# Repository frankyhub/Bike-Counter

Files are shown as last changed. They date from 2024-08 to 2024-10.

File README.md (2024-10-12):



<div align="center">

|[:skull:ISSUE](https://github.com/frankyhub/Bike-Counter/issues?q=is%3Aissue)|[:speech_balloon: Forum /Discussion](https://github.com/frankyhub/Bike-Counter/discussions)|[:grey_question:WiKi](https://github.com/frankyhub/Bike-Counter/wiki)||
|--|--|--|--|
| | | | |
||<a href="https://github.com/frankyhub/Bike-Counter/issues">|<a href="https://github.com/frankyhub/Bike-Counter/discussions">|<a href="https://github.com/frankyhub/Bike-Counter/releases">|
|| <a href="https://github.com/frankyhub/Bike-Counter/pulse" alt="Activity">| <a href="https://github.com/frankyhub/Bike-Counter/graphs/traffic">  |<a href="https://github.com/frankyhub?tab=stars"> |
</div>

# Bike-Counter

## Story
Der Bike-Counter zählt Bikes auf einer Nebenstraße in zwei unterschiedlichen Richtungen und sendet die Zählerstände an eine SQL-Datenbank. Es sollen nur Bikes gezählt werden und keine Fußgänger oder andere Fahrzeuge. Mit einem Dashboard werden die Zählerstände der Bikes angezeigt. Eine Auswertung zeigt die Durchfahrt der Bikes innerhalb der letzten 24 Stunden. Für die Erfassung der Bikes werden 2 Lichtschranken verwendet.

Vorteile des Bike-Counters: 
+ Verwendung von handelsüblichen Sensoren (Drucksensor, Lichtschranke ...)
+ Richtungserkennung der Fahrräder
+ Zählerstände auf einem Dashboard visualisiert
+ Auswertung der Bewegungen der letzten 24h
+ Nutzung der kostenlosen SQL-Datenbank des Providers (Strato)

## Hardware
+ 1 x ESP32
+ 2 x Lichtschranken PEM2D
+ 1 x Platine (Richtungserkennung)

## Software
+ Die Zählimpulse der Lichtschranken werden von der "Richtungserkennung-Platine" aufbereitet.
+ Der ESP32 übermittelt die Zählerstände an das PHP-Programm "post-data.php".
+ Die Zählerstände werden in einer SQL-Datenbank gespeichert und mit dem Dashboard "hoki-counter.php angezeigt.
+ Eine 24h-Auswertung kann mit dem Programm "auswertung.php" erfolgen.

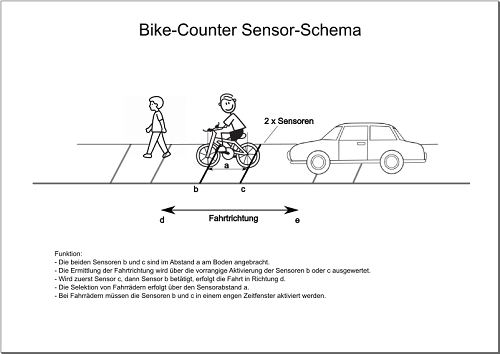
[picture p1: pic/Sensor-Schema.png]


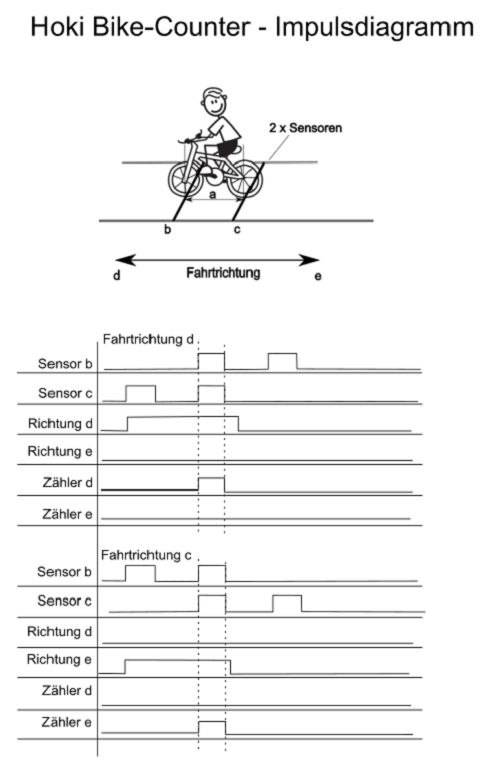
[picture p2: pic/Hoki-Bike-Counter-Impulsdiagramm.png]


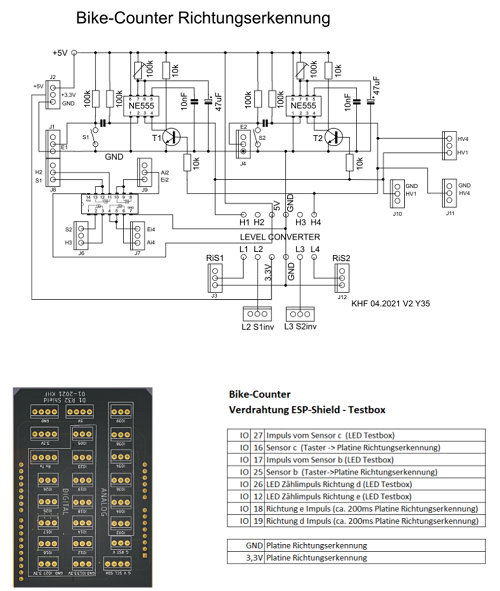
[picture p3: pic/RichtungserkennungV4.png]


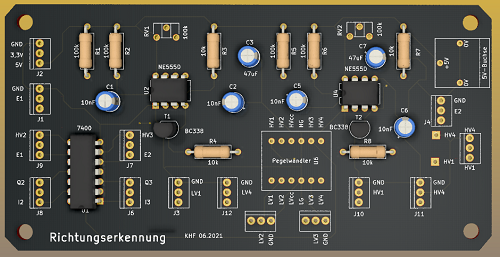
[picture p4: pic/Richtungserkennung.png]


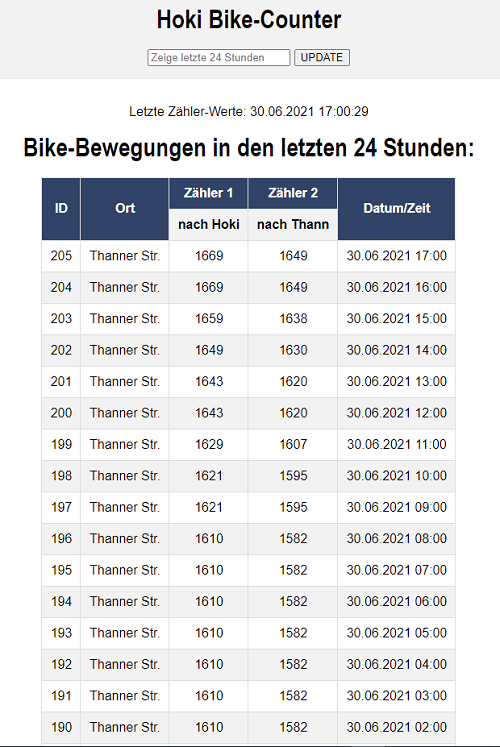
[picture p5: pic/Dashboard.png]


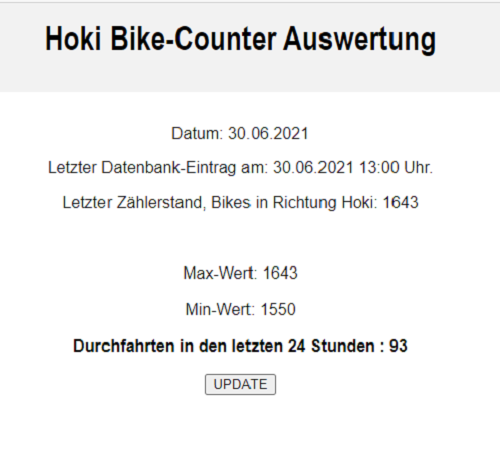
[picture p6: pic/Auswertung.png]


---

<div style="position:absolute; left:2cm; ">   
<ol class="breadcrumb" style="border-top: 2px solid black;border-bottom:2px solid black; height: 45px; width: 900px;"> <p align="center"><a href="#oben">nach oben</a></p></ol>
</div>  

---

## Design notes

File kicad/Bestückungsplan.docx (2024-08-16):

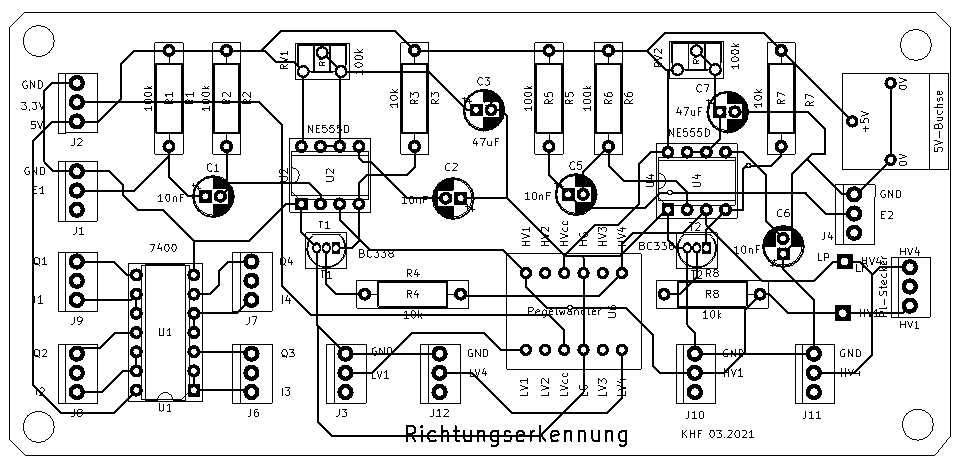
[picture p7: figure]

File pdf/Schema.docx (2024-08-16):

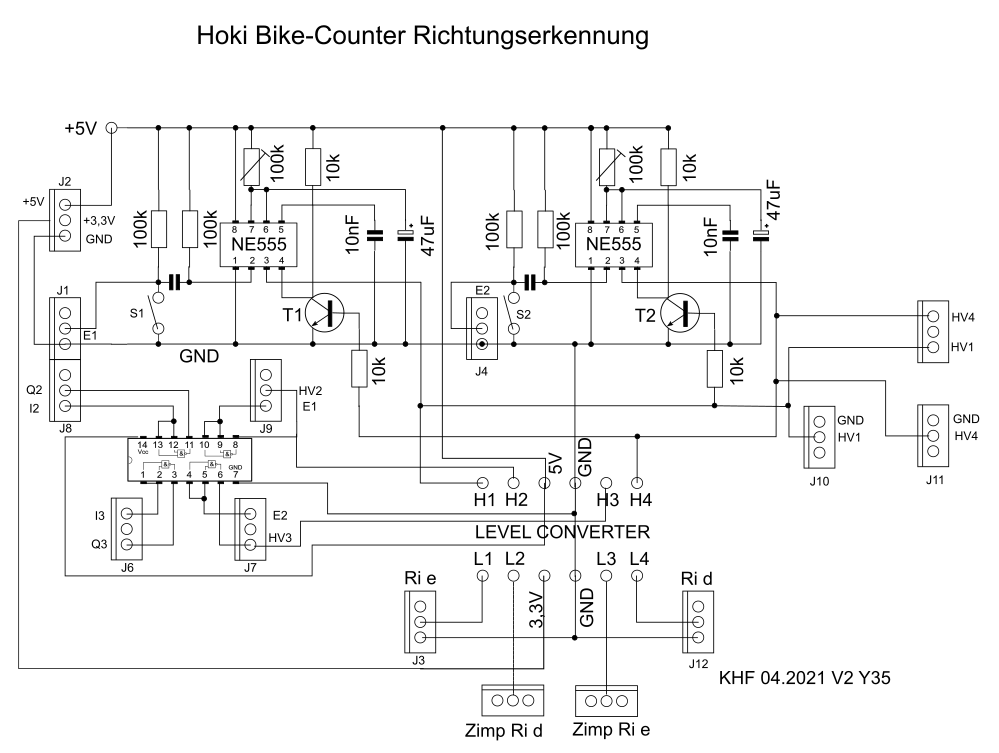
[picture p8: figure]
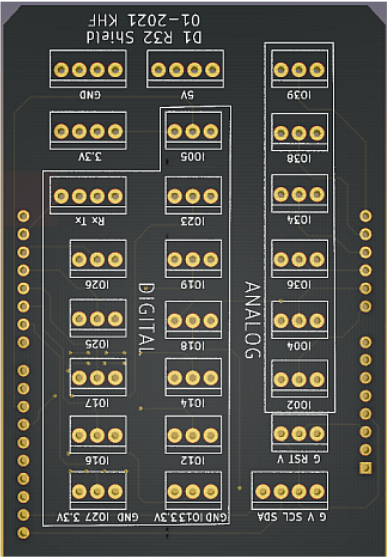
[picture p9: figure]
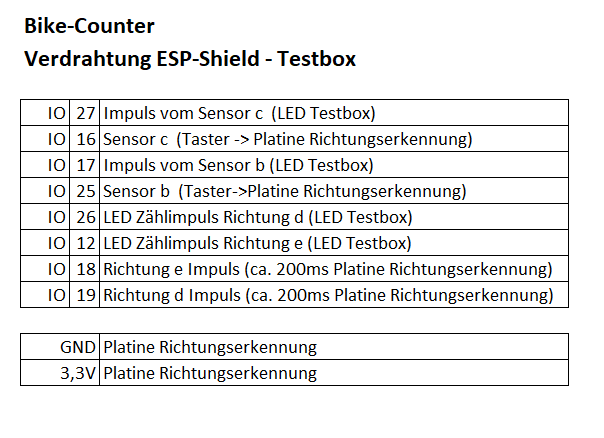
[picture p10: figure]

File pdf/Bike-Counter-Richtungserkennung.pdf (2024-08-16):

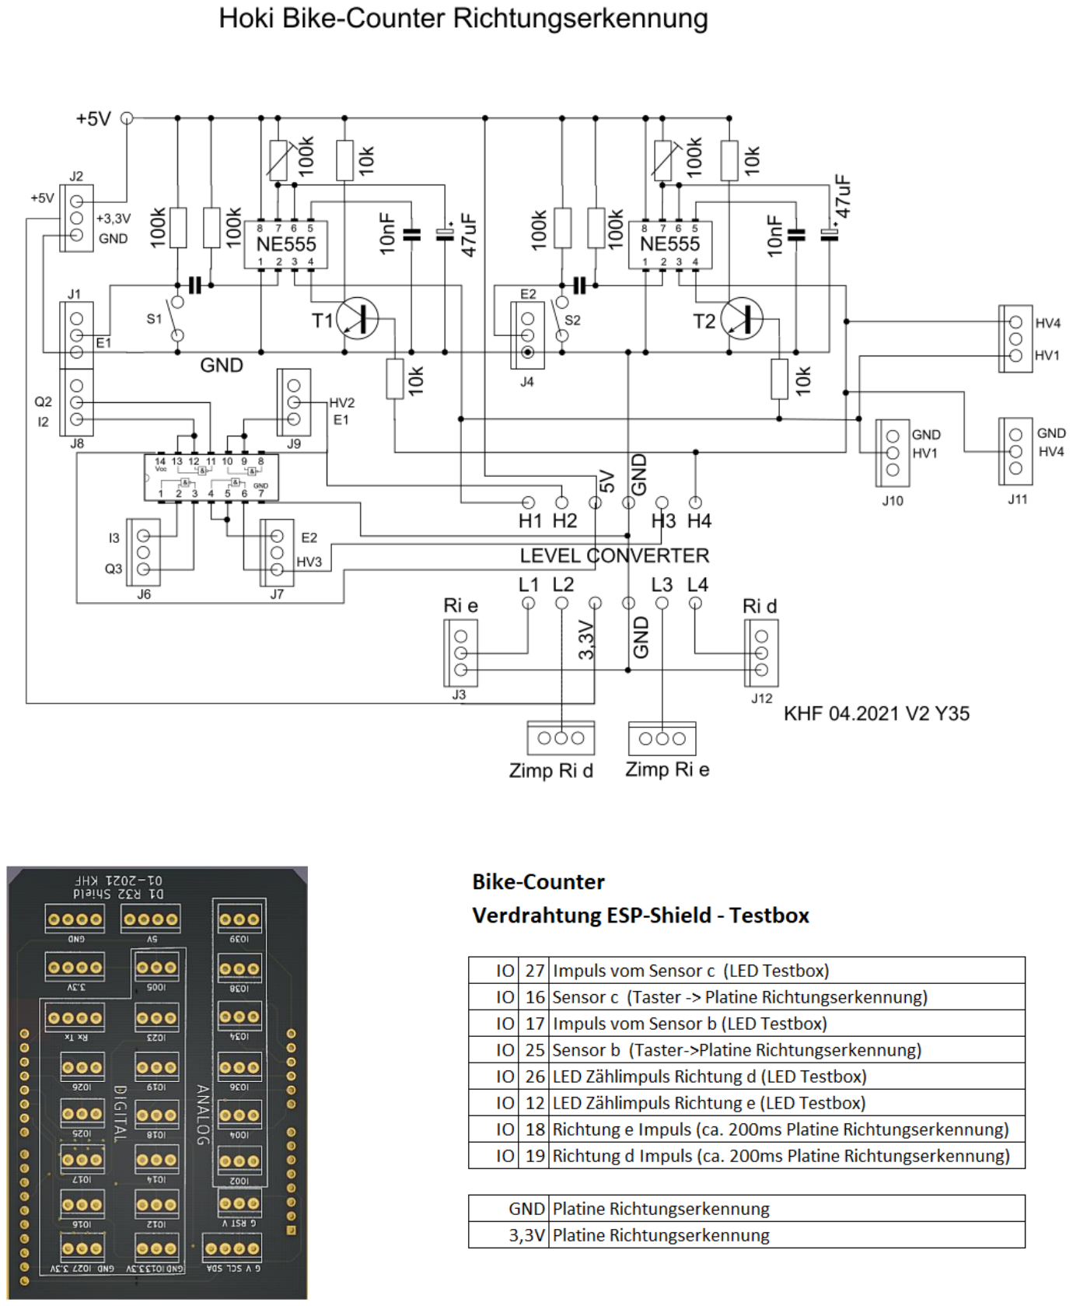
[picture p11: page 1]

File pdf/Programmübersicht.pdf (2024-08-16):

### Programm-Schema Hoki Bike-Counter frankyhub.de

Hoki Bike-Counter.ino

/hokidata/post-data.php | hoki-database.php (Zugangsdaten)
/hokidata /hoki-counter1.php | Browser-Aufruf
style.css | Browser-Style

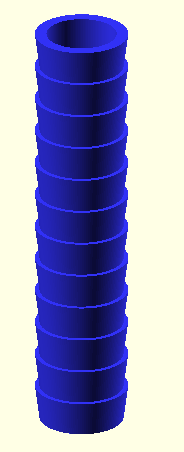
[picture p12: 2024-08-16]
pic/Reduzierung.png

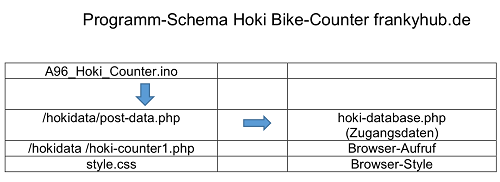
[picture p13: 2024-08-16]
pic/Programm-Schema.png

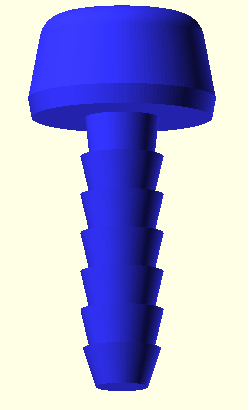
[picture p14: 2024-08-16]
pic/Stoepsel.png

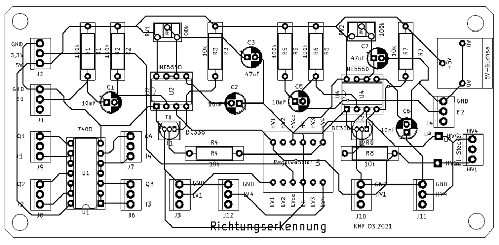
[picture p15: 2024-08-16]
pic/bestueckung.png

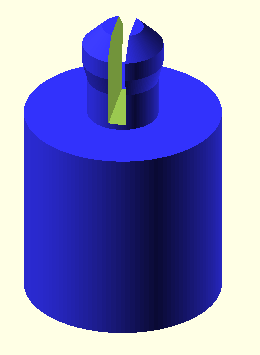
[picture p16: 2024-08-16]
pic/pin.png

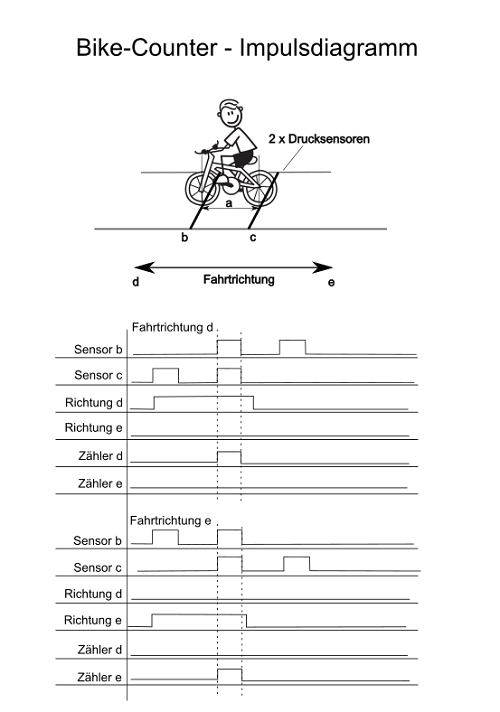
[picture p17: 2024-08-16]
pic/Bike-Couter-Impulsdiagramm.png

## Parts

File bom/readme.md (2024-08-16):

bill of materials

 Richtungserkennung

|Stück| Bezeichnung |
|--|---|
| 2| NE555 			 | 
| 1| 7400 oder 4011 	| 
| 1| 4 Kanal-Levelconverter 	| 
| 2| BC238 NPN 			 | 
| 2| Poti 100k			 	| 
| 4| 10nF	 		| 
| 2| 47uF			 | 
| 4| 100k		 |
| 4| 10k 	| 
| 14| JST 3pol | 
| 42| JST Stecker m/w | 
| 1| Platine		 |
| 4| Platinenfüße		 |

 ESP32

|Stück| Bezeichnung |
|--|---|
| 1| ESP32 			 | 
| 1| Shield 	|
| 4| Platinenfüße		 |
| 10| JST 3pol | 
| 3| JST 4pol | 
| 42| JST Stecker m/w | 
| 1| 2m Litze 	|

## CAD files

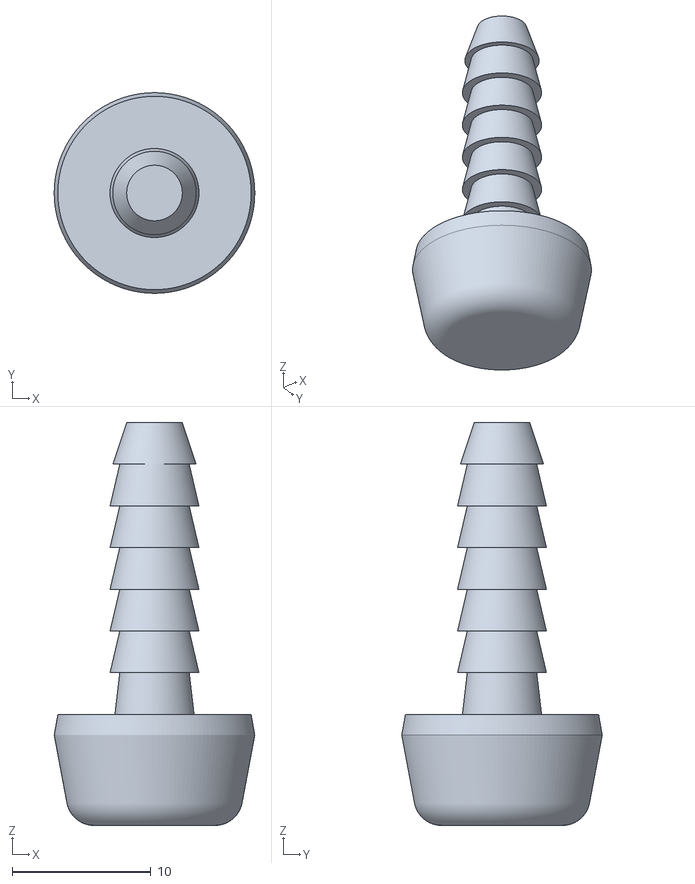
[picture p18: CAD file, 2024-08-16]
3D/Stoepsel.stl
14.4 x 14.4 x 29.0

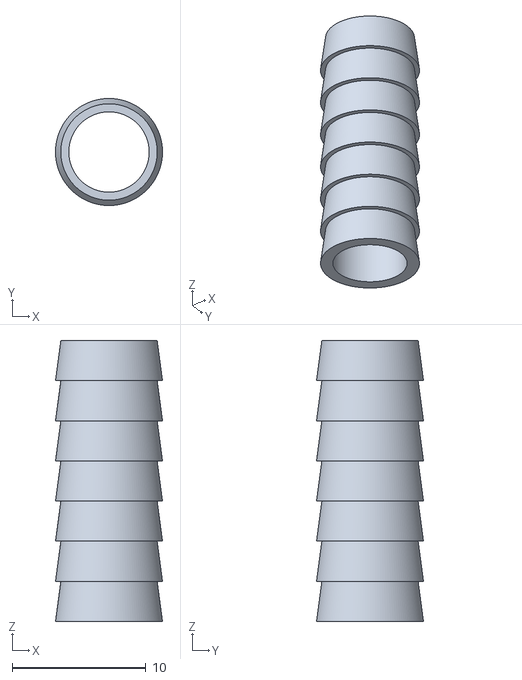
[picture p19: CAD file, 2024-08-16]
3D/Reduzierung.stl
8.00 x 8.00 x 21.0

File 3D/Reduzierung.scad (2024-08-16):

//Reduzierung Adapter-grüner Schlauch
$fn=130;

include <ma_lib/constants.scad>
use <ma_lib/shapes.scad>


r1=4;
r2=3.6;


color([0.2, 0.2, 1])
difference (){
union() {
//translate([0, 0, -2])
//rotate([180,0,0])
//cyl(l=8, d1=15, d2=12, 
//chamfer1=1.5, chamfang1=10,
//from_end=true, fillet2=2);
translate([0, 0, 20])
cylinder (3, r1, r2);
translate([0, 0, 17])
cylinder (3, r1, r2);
translate([0, 0, 14])
cylinder (3, r1, r2);
translate([0, 0, 11])
cylinder (3, r1, r2);
translate([0, 0, 8])
cylinder (3, r1, r2);
translate([0, 0, 5])
cylinder (3, r1, r2);
translate([0, 0, 2])
cylinder (3, r1, r2);
translate([0, 0, -1])
cylinder (3, r1, r2);
translate([0, 0, -4])
cylinder (3, r1, r2);
translate([0, 0, -7])
cylinder (3, r1, r2);    
translate([0, 0, -10])
cylinder (3, r1, r2);
translate([0, 0, -13])
cylinder (3, r1, r2);    
    
    
    
    
    
    
}
translate([0, 0, -15])
cylinder (40, d1=6, d2=6);
}

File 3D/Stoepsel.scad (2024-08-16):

//Druckschlauch-Stoepsel
$fn=130;

include <ma_lib/constants.scad>
use <ma_lib/shapes.scad>

color([0.2, 0.2, 1])

union() {
translate([0, 0, -2])
rotate([180,0,0])
cyl(l=8, d1=15, d2=12, 
chamfer1=1.5, chamfang1=10,
from_end=true, fillet2=2);
translate([0, 0, 20])
cylinder (3, d1=6, d2=4);
translate([0, 0, 17])
cylinder (3, d1=6.4, d2=5);
translate([0, 0, 14])
cylinder (3, d1=6.4, d2=5);
translate([0, 0, 11])
cylinder (3, d1=6.4, d2=5);
translate([0, 0, 8])
cylinder (3, d1=6.4, d2=5);
translate([0, 0, 5])
cylinder (3, d1=6.4, d2=5);
translate([0, 0, 2])
cylinder (3, d1=5.7, d2=5);
}

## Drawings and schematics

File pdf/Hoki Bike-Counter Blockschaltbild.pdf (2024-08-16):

## Hoki Bike-Counter Blockschaltbild Taster = Sensor

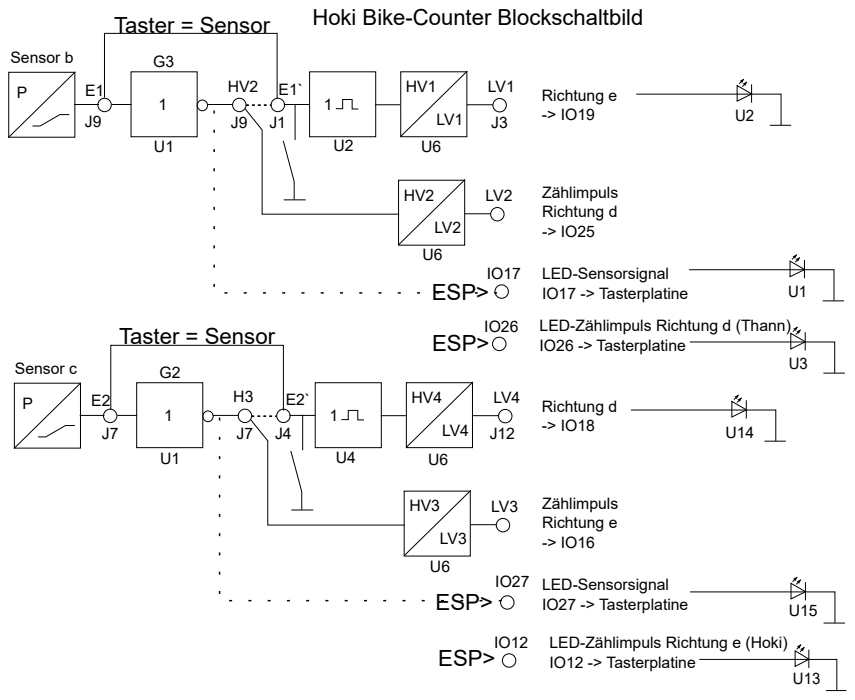
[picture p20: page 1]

LED-Sensorsignal
IO17 -> Tasterplatine
LED-Zählimpuls Richtung d (Thann)
IO26 -> Tasterplatine

LED-Zählimpuls Richtung e (Hoki)
IO12 -> Tasterplatine

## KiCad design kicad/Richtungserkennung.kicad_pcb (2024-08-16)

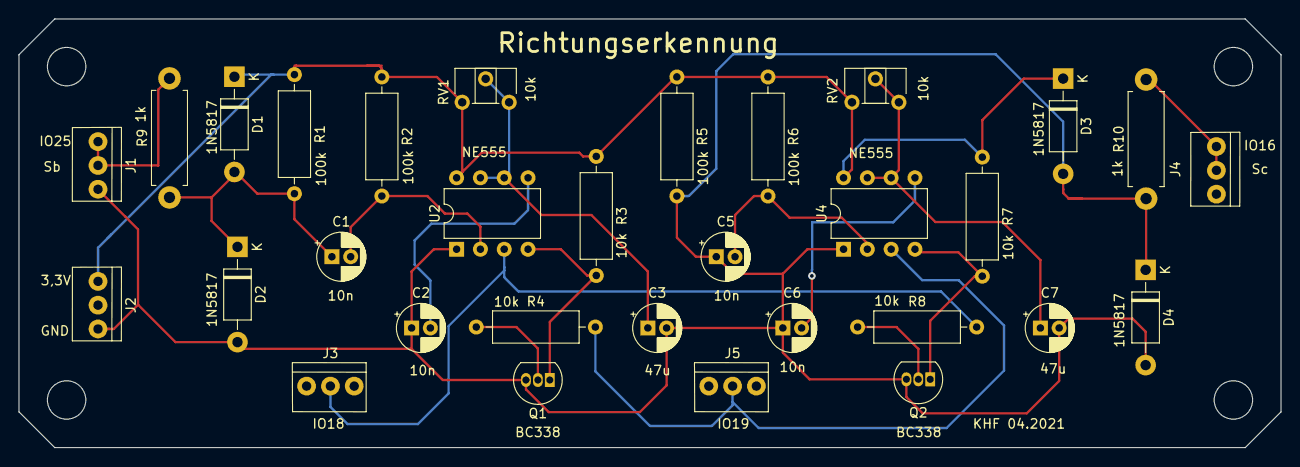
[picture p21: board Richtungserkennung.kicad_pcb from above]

Board: 2 copper layers, 134.6 x 45.7 mm, 31 parts (0 on the bottom side), 17 nets.

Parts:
C1, C2, C5, C6: 10nF; CP_Radial_D5.0mm_P2.00mm
C3, C7: CP; CP_Radial_D5.0mm_P2.00mm
D1, D2, D3, D4: 1N5817; D_DO-41_SOD81_P10.16mm_Horizontal
J1, J2, J3, J4, J5: PL-Stecker_3pol_ohne_Beschriftung; PL-Stecker3pol
Q1, Q2: BC338; TO-92_Inline
R1, R2, R5, R6: 100k; R_Axial_DIN0309_L9.0mm_D3.2mm_P12.70mm_Horizontal
R3, R7: 10k; R_Axial_DIN0309_L9.0mm_D3.2mm_P12.70mm_Horizontal
R4, R8: R; R_Axial_DIN0309_L9.0mm_D3.2mm_P12.70mm_Horizontal
R9, R10: 1k; R_Axial_DIN0411_L9.9mm_D3.6mm_P12.70mm_Horizontal
RV1: 10k; Potentiometer_Piher_PT-6-H_Horizontal
RV2: 100k; Potentiometer_Piher_PT-6-H_Horizontal
U2, U4: NE555D; DIP-8_W7.62mm

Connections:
unnamed: C1.1, D1.2, D2.1, R1.2, R9.1
unnamed: C1.2, R2.2, U2.2
unnamed: C2.1, C3.2, C5.1, C6.1, C7.2, D2.2, D3.2, D4.1, D4.2, J1.3, J2.3, Q1.3, Q2.3, R5.2, R10.1, U2.1, U4.1
unnamed: C2.2, U2.5
unnamed: C3.1, RV1.2, RV1.3, U2.6, U2.7
unnamed: C5.2, R6.2, U4.2
unnamed: C6.2, U4.5
unnamed: C7.1, RV2.2, RV2.3, U4.6, U4.7
unnamed: D1.1, D3.1, J2.1, R1.1, R2.1, R3.1, R5.1, R6.1, R7.1, RV1.1, RV2.1, U2.8, U4.8
unnamed: J1.1, J1.2, R9.2
unnamed: J3.2, R8.2, U2.3
unnamed: J4.1, J4.2, R10.2
unnamed: J5.2, R4.2, U4.3
unnamed: Q1.1, R3.2, U2.4
unnamed: Q1.2, R4.1
unnamed: Q2.1, R7.2, U4.4
unnamed: Q2.2, R8.1

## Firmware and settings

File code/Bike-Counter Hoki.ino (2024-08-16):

/* ESP32 Bike-Counter HOKI  frankyhub.de
 *  V1 28.06.2021 / 
 *  Board: ESP32vn IoT UNO
 *  Einstellungen:  https://dl.espressif.com/dl/package_esp32_index.json
 *                  C:\Users\User\Documents\Arduino\libraries
 */


#ifdef ESP32
  #include <WiFi.h>
  #include <HTTPClient.h>
#else
  #include <ESP8266WiFi.h>
  #include <ESP8266HTTPClient.h>
  #include <WiFiClient.h>
#endif

#include <Wire.h>
#include <Adafruit_Sensor.h>


const char* ssid = " ";
const char* password = " ";

const char* serverName = "http://frankyhub.de/hokidata/post-data.php";

String apiKeyValue = "tPmAT5Ab3j7F9";
String sensorName = "Counter 1";
String sensorLocation = "Thanner Str.";



//--------Sensor 1 und 2 --------------------------------
int Ta1 = 25; //Sensor b Imp 1a (Platine Impulsaufbereitung)
int Ts1 = 0; // Status des Sensors 
int L1 = 17; //LED Impuls vom Sensor b

int Ta2 = 16; //Sensor c Imp 2a (Platine Impulsaufbereitung)
int Ts2 = 0; // Status des Sensors
int L2 = 27; //LED 2 Impuls vom Sensor c

int Ld = 26; //Zählimpuls Richtung d

int Le = 12; //Zählimpuls Richtung e
//----------------------------------------

//--------Richtung d oder e --------------------------------

int Rd = 18; //Richtung d Imp 1a (Platine Richtungserkennung)
int Rds = 0; // Status Richtung d 
int Re = 19; //Richtung e Imp 2a (Platine Richtungserkennung)
int Rde = 0; // Status Richtung e
//----------------------------------------


 //Counter d Richtung Thann
int countd = 1370;//----------------------------------------//--------------- Datenbankwert aktualiesieren ! -------------------------//----------------------------------------
String count_d;
//----------------------------------------



 //Counter e Richtung Hoki
int counte = 1410;//----------------------------------------//---------------- Datenbankwert aktualiesieren ! -----------------------//----------------------------------------
String count_e;
//----------------------------------------


//----------Sendeintervalle (1h) ------------------------------
unsigned long lastTime = 0;
// Timer für 10 Minuten (600000)
//unsigned long timerDelay = 600000;
// Timer für 30 Sekunden (30000)
//unsigned long timerDelay = 10000;
// Timer für 1h:3 600 000
unsigned long timerDelay = 3598900; //-------------------------------------------28.06.2021------------------------//----------------------------------------

void setup() {
  
  //-----------------------------------------
  pinMode(Ta1, INPUT_PULLUP); 
  pinMode(L1, OUTPUT);      
  //-----------------------------------------

  //-----------------------------------------
  pinMode(Ta2, INPUT_PULLUP); 
  pinMode(L2, OUTPUT);      
  //-----------------------------------------
  pinMode(Ld, OUTPUT);
  pinMode(Le, OUTPUT);  
  //-----------------------------------------
  pinMode(Rd, INPUT);
  pinMode(Re, INPUT);  
  //----------------------------------------- 
  Serial.begin(115200);

  //-------WiFi ----------------------------------
  WiFi.begin(ssid, password);
  Serial.println("Verbunden");
  while(WiFi.status() != WL_CONNECTED) {
    delay(500);
    Serial.print(".");
  }
  Serial.println("");
  Serial.print("Verbunden mit WiFi IP Addresse: ");
  Serial.println(WiFi.localIP());

  
  Serial.println("Timer ist auf 1h eingestellt (timerDelay-Variable), es dauert 1h, bis die erste Lesung veröffentlicht wird.");


//------------------------------------------- Post nach Reset ---------------------------------------------
HTTPClient http;

      // Domain Name
      http.begin(serverName);

      // Header
      http.addHeader("Content-Type", "application/x-www-form-urlencoded");

      // Vorbereiten der HTTP POST-Anforderungsdaten
      String httpRequestData = "api_key=" + apiKeyValue + "&sensor=" + sensorName
                            + "&location=" + sensorLocation + "&value1=" + countd+ "&value2=" + counte;
     
      Serial.print("httpRequestData: ");
      Serial.println(httpRequestData);
      int httpResponseCode = http.POST(httpRequestData);
      if (httpResponseCode>0) {
        Serial.print("HTTP Response code: ");
        Serial.println(httpResponseCode);
      }  
}

//------------------------------------------------------------------------------------------------------------
void loop() {

//-----------------------------------------  

  count_d =  String(countd);
  count_e =  String(counte);
  
//-----------------------------------------

//-------- Sensor b ---------------------------------
  Ts1 = digitalRead(Ta1);
  delay(5);
     if (Ts1 == HIGH) 
     {     
    digitalWrite(L1, HIGH);
     }
                else  
                {
                digitalWrite(L1, LOW);
                }
                
  //-------- Sensor c ---------------------------------
  Ts2 = digitalRead(Ta2);
  delay(5);
     if (Ts2 == HIGH) 
     {     
    digitalWrite(L2, HIGH);
     }
                else  
                {
                digitalWrite(L2, LOW);
                }

//------- Richtung einlesen ----------------------------------

  Rds = digitalRead(Rd);
  delay(5);

//------------------------------------------------------------
  Rde = digitalRead(Re);
  delay(5);


  //---------- Zähler d -------------------------------
                if(Ts1 == 1 && Ts2 == 1 && Rds == 1)
                //if(Ts1 == 1 && Ts2 == 1)
                {
                countd++;
                digitalWrite(Ld, HIGH);
                Serial.println ("Zählerstand Richtung d (Thann): ");
                Serial.println(count_d);
                delay(500);
                digitalWrite(Ld, LOW);
                }

//-----------------------------------------

  //---------- Zähler e -------------------------------
                if(Ts1 == 1 && Ts2 == 1 && Rde == 1)
                {
                counte++;
                digitalWrite(Le, HIGH);
                Serial.println ("Zählerstand Richtung e (Hoki): ");
                Serial.println(count_e);
                delay(500);
                digitalWrite(Le, LOW);
                }

//-----------------------------------------
  
  //---------- HTTP POST ----------------------
  if ((millis() - lastTime) > timerDelay) {
    //Check WiFi connection status
    if(WiFi.status()== WL_CONNECTED){
      HTTPClient http;

      // Domain Name
      http.begin(serverName);

      // Header
      http.addHeader("Content-Type", "application/x-www-form-urlencoded");

      // Vorbereiten der HTTP POST-Anforderungsdaten
      String httpRequestData = "api_key=" + apiKeyValue + "&sensor=" + sensorName
                            + "&location=" + sensorLocation + "&value1=" + countd + "&value2=" + counte;
     
       
      Serial.print("httpRequestData: ");
      Serial.println(httpRequestData);



      // HTTP POST-Anforderung senden
      int httpResponseCode = http.POST(httpRequestData);

      if (httpResponseCode>0) {
        Serial.print("HTTP Response code: ");
        Serial.println(httpResponseCode);
      }
      else {
        Serial.print("Error code: ");
        Serial.println(httpResponseCode);
      }
      // Free resources
      http.end();
    }
    else {
      Serial.println("WiFi Disconnected");
    }
    lastTime = millis();
  }
}
